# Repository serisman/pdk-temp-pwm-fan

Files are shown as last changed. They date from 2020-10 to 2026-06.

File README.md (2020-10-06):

# pdk-temp-pwm-fan
A temperature controlled PWM fan controller using an inexpensive (3 cent) 8-bit Padauk microcontroller.

### Links
- [Firmware](firmware/)
- [PCB](pcb-u06/)

This fan controller drives a common 4-pin PC fan, by sending a 25 kHz PWM signal with a varying duty cycle.
The duty cycle is adjusted up or down based on a high and low temperature set point.
- If the temperature is below the low set point, the PWM duty is decreased by 1 every 1/3 second until it the fan is off (or as slow as it can go).
- If the temperature is above the high set point, the PWM duty cycle is increased by 1 times the number increments above the high set point every 1/3 second until the fan is fully on.

The temperature is measured using a 10K NTC thermistor between VCC and a 1K resistor to GND forming a voltage divider.
- The output of this voltage divider is fed into the Padauk microcontroller's Comparator + input.
- The Comparator's - input is connected to an internally generated voltage source that can be set to 16 different voltage levels between GND and 1/2 VCC.
- So, by changing the internal voltage source, the Comparator can be checked to see if the NTC's output is greater or less than a set point.

This temperature measurement isn't particularly precise, but should suffice for crude temperature control requirements,
like cooling down a heatsink in a power supply or UPS, with minimal power loss and noise when cooling isn't required.

### Schematic
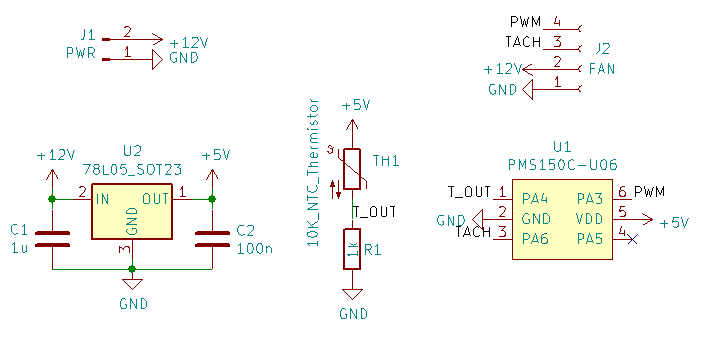
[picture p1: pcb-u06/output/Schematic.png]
Schematic
> 

### Compatibility
This project is currently intended to be run on the PMS150C Padauk microcontrollers,
but it should be able to be run on pretty much any other Padauk microcontrollers that have a Comparator (most)
and that are supported by SDCC and the Easy PDK Programmer.

### Images
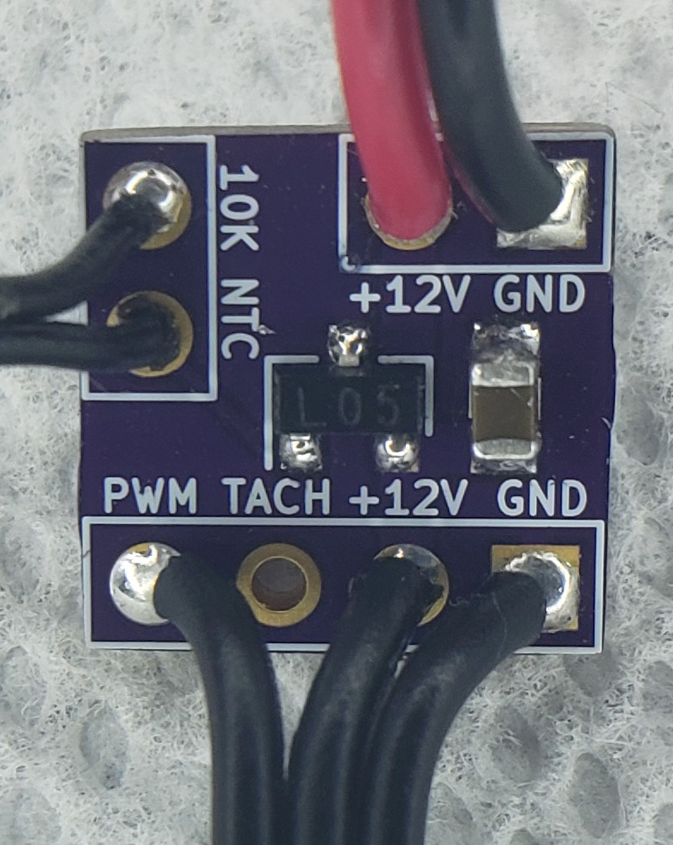
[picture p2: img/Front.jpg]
Front

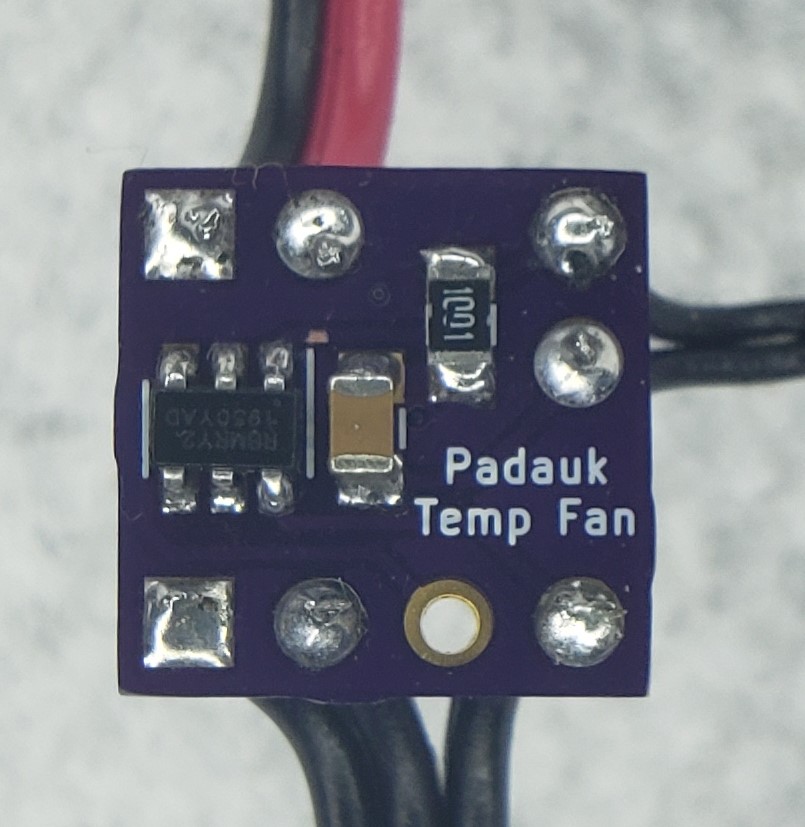
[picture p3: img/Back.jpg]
Back

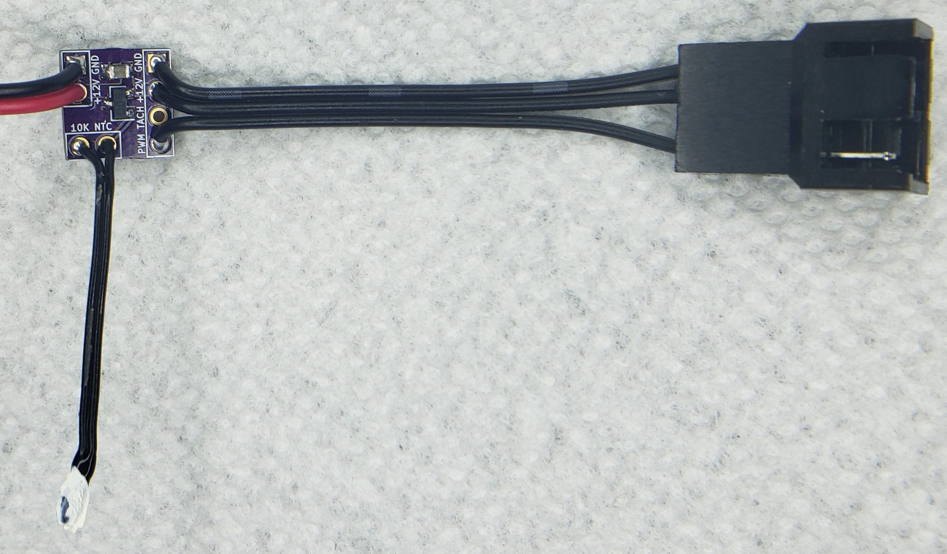
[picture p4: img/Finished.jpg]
Finished!


### Copyright and License:
- Copyright (C) 2020 - serisman (github@serisman.com)
- License: [GPL v3 (or later)](LICENSE)

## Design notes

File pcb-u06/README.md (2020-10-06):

# pcb-u06 (pdk-temp-pwm-fan)

### Schematic
> Schematic

### PCB

This PCB design was created with KiCad, and has been [shared on OSHPARK](https://oshpark.com/shared_projects/2kFmPXyn).
There are also gerber files available in the [output/gerber/](output/gerber/) directory.

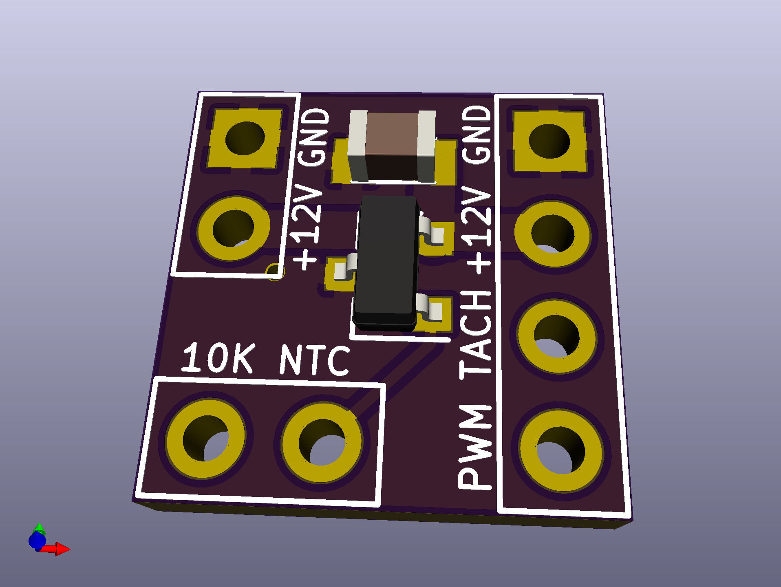
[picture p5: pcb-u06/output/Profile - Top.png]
3D Top

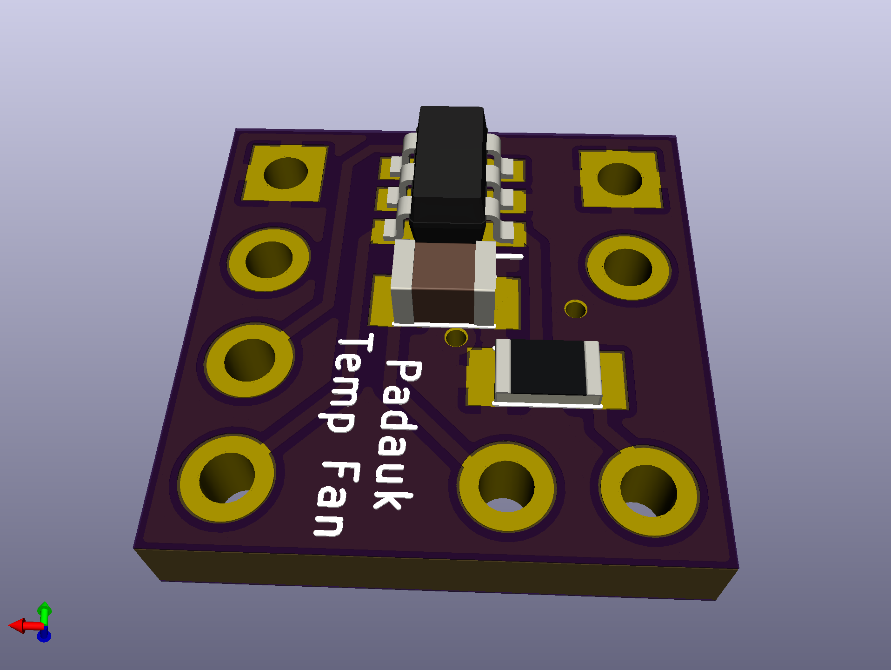
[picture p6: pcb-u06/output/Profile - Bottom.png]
3D Bottom

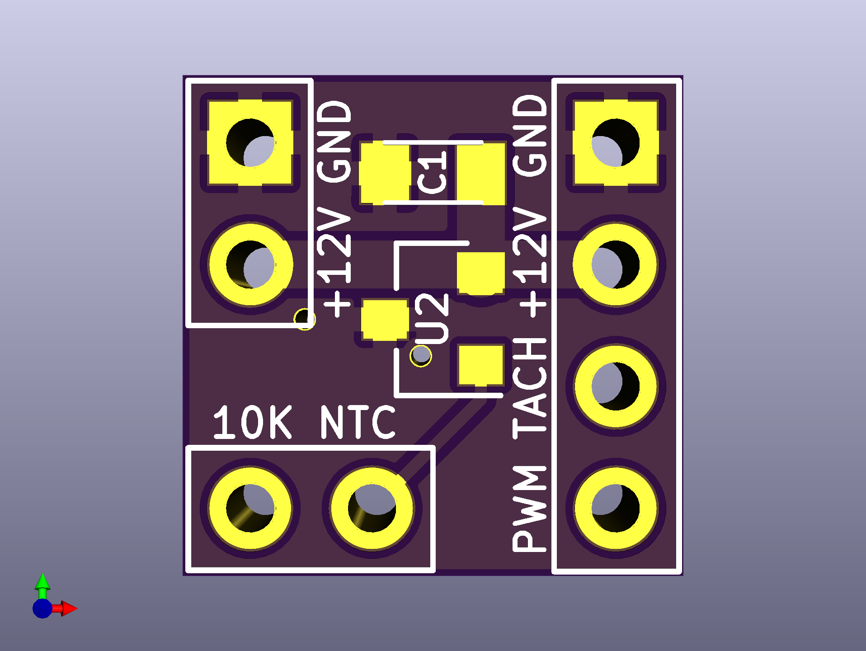
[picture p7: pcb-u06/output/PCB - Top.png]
PCB Top

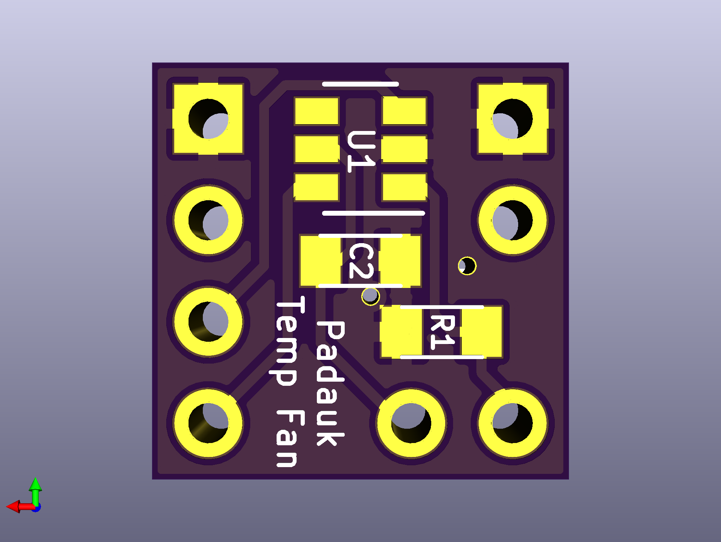
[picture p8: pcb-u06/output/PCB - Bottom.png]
PCB Bottom


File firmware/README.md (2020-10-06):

# firmware ([pdk-temp-pwm-fan](https://github.com/serisman/pdk-temp-pwm-fan/))

### Toolchain:
- The open-source [Small Device C Compiler (SDCC)](http://sdcc.sourceforge.net/)
  - Requires version 3.9.0 or newer - version 4.0.0+ preferred
- The open-source [Easy PDK Programmer](https://github.com/free-pdk/easy-pdk-programmer-software)
  - Requires version 1.3 or newer
- The open-source [pdk-includes](https://github.com/free-pdk/pdk-includes) repository
  - Integrated via local copy into the pdk/ directory
- The open-source [easy-pdk-includes](https://github.com/free-pdk/easy-pdk-includes) repository
  - Integrated via local copy into the easy-pdk/ directory
- Also requires 'make' and other common build tools

### Build Commands:
```
make clean
make build
make size (also calls build)
make program (also calls size which calls build)
make run
```
> Note: These commands can be chained as well.  i.e. `make clean program run`

### Customization:
Edit the variables at the top of the Makefile to:
- **DEVICE**: Use a different Padauk MCU (defaults to PFS154)
- **TARGET_VDD_MV**: Use a different voltage while calibrating the internal oscillator (IHRC or ILRC) (defaults to 4000mV)

> Note: All of these variables can be changed on the commandline as well.  i.e. `make DEVICE=PFS173 clean program run` 

### Compatibility
This project is currently intended to be run on the PMS150C Padauk microcontrollers,
but it should be able to be run on pretty much any other Padauk microcontrollers that have a Comparator (most)
and that are supported by SDCC and the Easy PDK Programmer.

### Build Stats
- Code Size: ~126 words
- RAM usage: 1 bytes + stack

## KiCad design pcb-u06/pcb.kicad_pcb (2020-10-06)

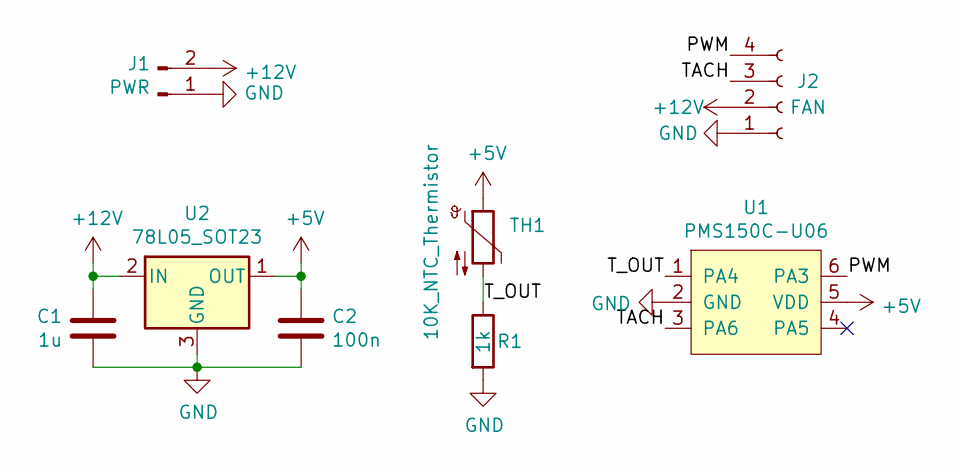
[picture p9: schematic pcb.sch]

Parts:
C1: 1u; C_0805
C2: 100n; C_0805
J1: PWR; PinSocket_1x02_P2.54mm_Vertical
J2: FAN; PinSocket_1x04_P2.54mm_Vertical
R1: 1k; R_0805
TH1: 10K_NTC_Thermistor; PinSocket_1x02_P2.54mm_Vertical
U1: PMS150C-U06; SOT-23-6
U2: 78L05_SOT23; SOT-23

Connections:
+5V: C2.1, TH1.1, U1.5 (VDD), U2.1 (OUT)
+12V: C1.2, J1.2, J2.2, U2.2 (IN)
/PWM: J2.4, U1.6 (PA3)
/TACH: J2.3, U1.3 (PA6)
/T_OUT: R1.1, TH1.2, U1.1 (PA4)
GND: C1.1, C2.2, J1.1, J2.1, R1.2, U1.2 (GND), U2.3 (GND)

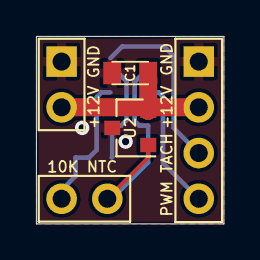
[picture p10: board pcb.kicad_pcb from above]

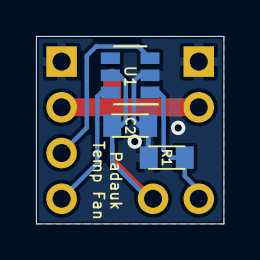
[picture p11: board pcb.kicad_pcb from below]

Board: 2 copper layers, 10.4 x 10.4 mm, 8 parts (3 on the bottom side), 6 nets.

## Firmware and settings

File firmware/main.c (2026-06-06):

/*
  main.c: Main program code for the PDK temperature controlled PWM fan project.

  Copyright (C) 2020  serisman  <github@serisman.com>

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
  ----------------------------------------------------------------------
*/

#include <stdint.h>
#include <pdk/device.h>
#include <easy-pdk/calibrate.h>
#include "ntc.h"

#define FAN_BIT           3   // Fan is placed on the PA3 pin (Port A, Bit 3), which is also TM2PWM
#define NTC_BIT           4   // 10k NTC is placed on the PA4 pin (Port A, Bit 4), which is also Comp+/Comp-

#define TRIGGER_LOW       NTC_1K_TRIGGER_45C
#define TRIGGER_HIGH      NTC_1K_TRIGGER_50C

void everyTick(void) {
	static uint8_t pwm = 0;

	// Decrement Fan PWM duty if NTC is < low trigger point
	GPCS = (uint8_t)(GPCS_COMP_RANGE4 | (TRIGGER_LOW & 0x0F));
	if (pwm > 0 && (GPCC & (1 << GPCC_COMP_RESULT_BIT)) == GPCC_COMP_RESULT_NEGATIVE) {
		pwm--;
	}

	// Increment Fan PWM duty, +1 for each step >= high trigger point where NTC is > step trigger point
	for (uint8_t t=TRIGGER_HIGH; t<=0x0F; t++) {
		GPCS = (uint8_t)(GPCS_COMP_RANGE4 | t);
		if (pwm < 255 && (GPCC & (1 << GPCC_COMP_RESULT_BIT)) == GPCC_COMP_RESULT_POSITIVE) {
	    pwm++;
		} else {
			break;
		}
	}

	// Set Fan PWM
	if (pwm) {
		TM2B = pwm;
		TM2C = (uint8_t)(TM2C_MODE_PWM | TM2C_OUT_PA3 | TM2C_CLK_IHRC);  // Ensure PWM is enabled
	} else {
		TM2C = 0x00;          // Disable PWM
		PA &= ~(1<<FAN_BIT);  // Force FAN PWM Output LOW
	}
}

void interrupt(void) __interrupt(0) {
  if (INTRQ & INTRQ_T16) {        // T16 interrupt request?
    everyTick();
    INTRQ &= ~INTRQ_T16;          // Mark T16 interrupt request processed
  }
}

// Main program
void main(void) {

  // Disable wake-up on un-used pins to save power
  PADIER = 0x00;
#if defined(PBDIER)
  PBDIER = 0x00;
#endif
#if defined(PCDIER)
  PCDIER = 0x00;
#endif

  // Initialize pins
  PAC = (1<<FAN_BIT);         // Set Fan Pin as output

	// Setup PWM for Fan
	//  frequency = F_TIMER / (256 x TM2S[6:5] x (TM2S[4:0] + 1))
	//  duty = ((TM2B[7:0] + 1) / 256) * 100%
	TM2B = 0;
	TM2S = (uint8_t)(TM2S_SCALE_DIV2); // 25 kHz (12.8 mHz / (256 * 1 * 2))
	TM2C = (uint8_t)(TM2C_MODE_PWM | TM2C_OUT_PA3 | TM2C_CLK_IHRC);

  // Setup/enable the Comparator for checking Temperature (i.e. NTC(+) > VINT(-))
  GPCC = (uint8_t)(GPCC_COMP_ENABLE | GPCC_COMP_MINUS_VINT_R | GPCC_COMP_PLUS_PA4);

  // Setup timer16 (T16) interrupt to tick every 327.68 mS (3.05175 Hz)
  T16M = (uint8_t)(T16M_CLK_IHRC | T16M_CLK_DIV64 | T16M_INTSRC_15BIT);
  T16C = 0;

  INTEN = INTEN_T16;
  INTRQ = 0;
  __engint();                     // Enable global interrupts

  // Main processing loop
  while (1) {
    __stopexe();                  // Go to sleep (timer16 will wake us back up)
  }
}

#if SDCC >= 40300
    #define SDCC_EXTERNAL_STARTUP __sdcc_external_startup
#else
    #define SDCC_EXTERNAL_STARTUP _sdcc_external_startup
#endif

// Startup code - Setup/calibrate system clock
unsigned char SDCC_EXTERNAL_STARTUP(void) {
  // Set FUSE:
  // - 1.8v LVR (if available)
  // - Normal IO Drive (if available)
  // - Fast Bootup (if available)
  // - Security Off
#if defined(FUSE_LVR_1V8) && defined(FUSE_IO_DRV_NORMAL) && defined(FUSE_BOOTUP_FAST)
  PDK_SET_FUSE(FUSE_BOOTUP_FAST | FUSE_IO_DRV_NORMAL | FUSE_LVR_1V8 | FUSE_SECURITY_OFF);
#elif defined(FUSE_LVR_1V8)
  PDK_SET_FUSE(FUSE_LVR_1V8 | FUSE_SECURITY_OFF);
#elif defined(FUSE_IO_DRV_NORMAL) && defined(FUSE_BOOTUP_FAST)
  PDK_SET_FUSE(FUSE_BOOTUP_FAST | FUSE_IO_DRV_NORMAL | FUSE_SECURITY_OFF);
#elif defined(FUSE_BOOTUP_FAST)
  PDK_SET_FUSE(FUSE_BOOTUP_FAST | FUSE_SECURITY_OFF);
#else
  PDK_SET_FUSE(FUSE_SECURITY_OFF);
#endif

  // Set LVR:
  // - 1.8v (if available)
  // - otherwise 2.0v (if available)
#if defined(MISCLVR_1V8)
  MISCLVR = (uint8_t) MISCLVR_1V8;
#elif defined(MISCLVR_2V)
  MISCLVR = (uint8_t) MISCLVR_2V;
#endif

  // Initialize the system clock (CLKMD register) for IHRC/64
  PDK_SET_SYSCLOCK(CLKMD_IHRC_DIV64);

  // Insert placeholder code to tell EasyPdkProg to calibrate the IHRC internal oscillator for 12.8 MHz operation.
  EASY_PDK_CALIBRATE_IHRC(12800000/64, TARGET_VDD_MV);

  return 0;   // Return 0 to inform SDCC to continue with normal initialization.
}

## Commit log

2020-10-06 Initial Version
    [pcb-B_Cu.gbr, pcb-B_Mask.gbr, pcb-B_Paste.gbr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]
2020-10-06 Add supporting docs
    [NTC Calc.xlsx]

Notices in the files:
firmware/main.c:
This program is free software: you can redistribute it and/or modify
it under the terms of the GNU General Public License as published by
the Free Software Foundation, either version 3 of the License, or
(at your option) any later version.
